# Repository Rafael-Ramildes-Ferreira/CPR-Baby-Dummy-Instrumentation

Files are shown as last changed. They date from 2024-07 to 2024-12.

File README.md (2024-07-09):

# CPR-Baby-Dummy-Instrumentation
The goal is to apply sensors to verify CPR training on a Baby dummy. This is part of curse of Projeto Integrador (DAS5104) in UFSC, 2024, 1st semester.

The prject started at 2023/2 and the code made that semester can be seen [here](https://github.com/PSCoes/Projeto_Integrador).

The ESP code was developed using [Platform.io](https://platformio.org)

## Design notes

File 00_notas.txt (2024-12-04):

-(ptrdiff_t)boxq->tail era pra dar menor que zero para indexar boxq->queue, mas está dando positivo, o que dá LoadProhibited.
O próprio endereço de boxq->queue está dando errado.

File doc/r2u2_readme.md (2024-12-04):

# Using R2U2 on ESP32
The code used is provided in . However it is a demostration made to run in Linux. In order to run it in ESP32, some changes had to be done in the source code, such as the following:

### Padding
Paddings ware added to structures to combat differences in memory alignment. These structures are:
- `r2u2_mltl_instruction_t`
- `r2u2_boxq_t`     
- `r2u2_instruction_t`

Beyond adding the paddings in the struct definition it is also necessary to add it when the structrue is created with {**values}
Tests ware only made in past time formulas, some other structures may also need padding when different formulas are used

### Memory bound sizes
Standard monitor implementation is to big for the internal memory of most microcontrollers, so alternatives sizes ware added to implement the monitor and are know used in the library code in place of the old larger values.
These values ware placed as defines in `internals/bounds.h`

----

This is still not a complete list, more changes may be necessary.

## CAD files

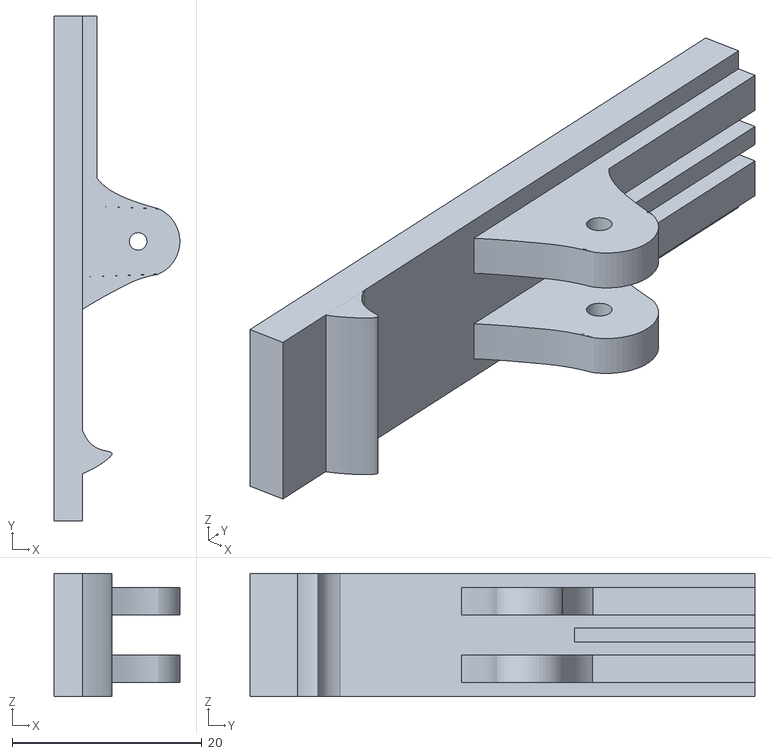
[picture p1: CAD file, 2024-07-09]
hardware/conector clip/pt_baixo_1_5mm.stl
13.2 x 53.2 x 13.0

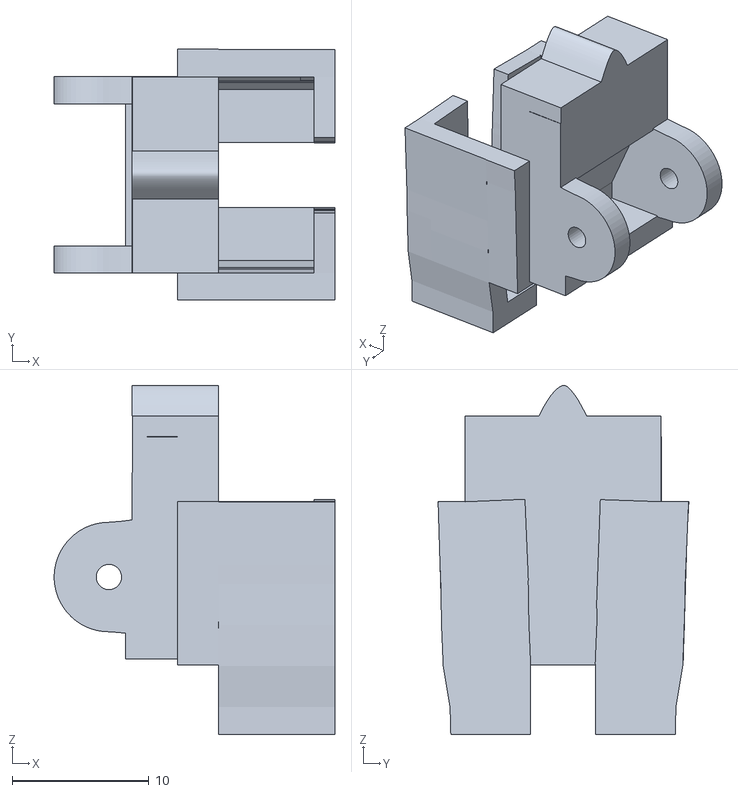
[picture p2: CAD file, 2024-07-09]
hardware/conector clip/pt_cima_1mm.stl
20.5 x 18.3 x 25.5

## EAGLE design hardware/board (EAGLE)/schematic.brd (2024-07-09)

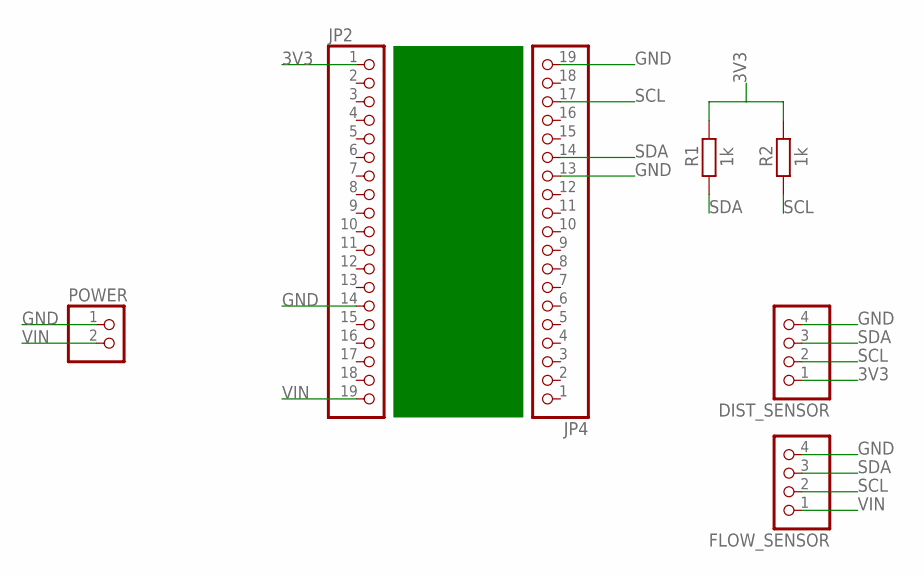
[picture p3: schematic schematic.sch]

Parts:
DIST_SENSOR: PINHD-1X4; 1X04
FLOW_SENSOR: PINHD-1X4; 1X04
JP2, JP4: PINHD-1X19; 1X19
POWER: PINHD-1X2; 1X02
R1, R2: 1k; 0207/10

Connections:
3V3: DIST_SENSOR.1, JP2.1, R1.2, R2.2
GND: DIST_SENSOR.4, FLOW_SENSOR.4, JP2.14, JP4.13, JP4.19, POWER.1
SCL: DIST_SENSOR.3, FLOW_SENSOR.3, JP4.17, R2.1
SDA: DIST_SENSOR.2, FLOW_SENSOR.2, JP4.14, R1.1
VIN: FLOW_SENSOR.1, JP2.19, POWER.2

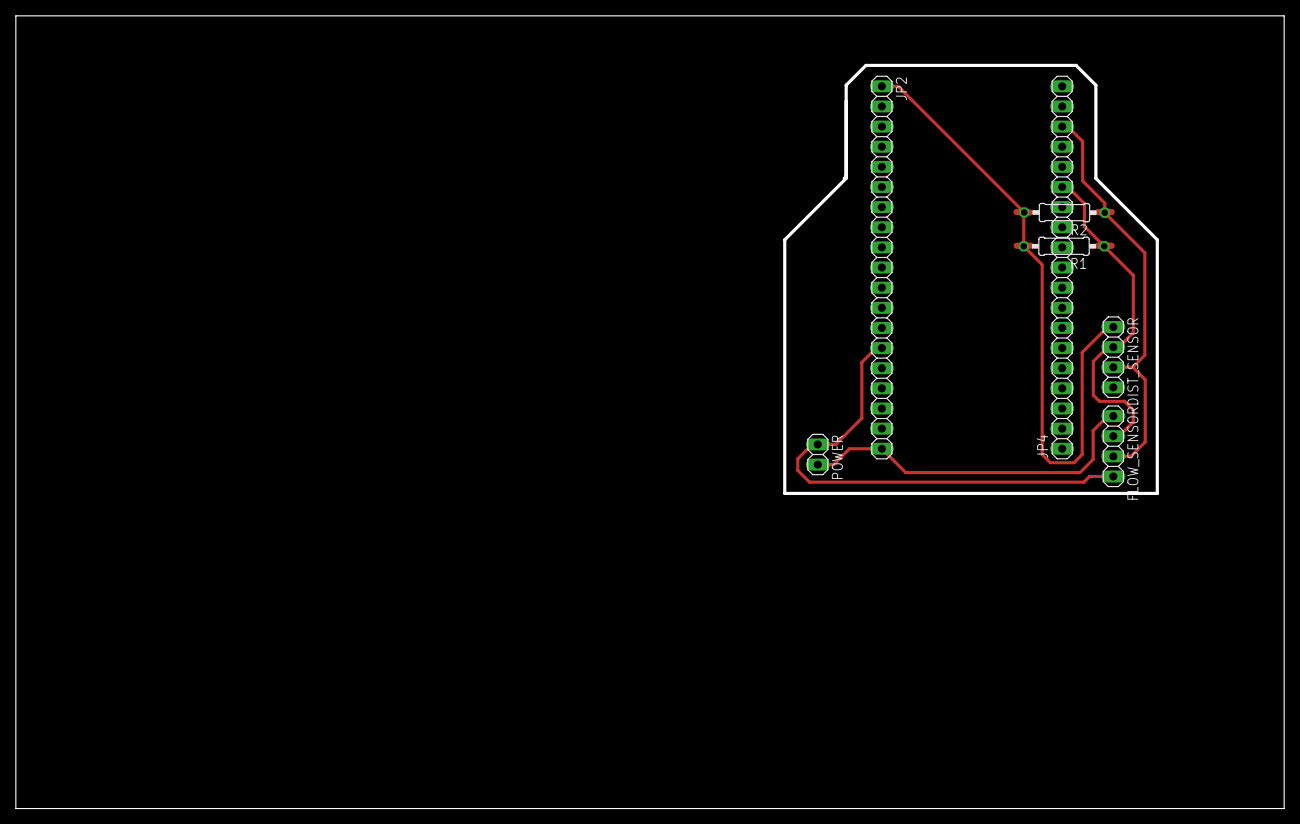
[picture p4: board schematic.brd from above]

Board: 2 copper layers, 160.0 x 100.0 mm, 7 parts (0 on the bottom side), 5 nets.

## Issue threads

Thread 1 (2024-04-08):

Measured value in sensor error

Rafael-Ramildes-Ferreira, 2024-04-08:
Find out why the measured value was set to 200 when error happens in the distance sensor reading

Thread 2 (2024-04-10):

Fix timer overflow

Rafael-Ramildes-Ferreira, 2024-04-10:
millis can overflow, it's used in last_peak and last_valley
- [ ] Fix overflow
- [ ] Change data type

Rafael-Ramildes-Ferreira, 2024-07-01:
"[...] Esse número irá sofrer overflow (chegar ao maior número possível e então voltar pra zero), após aproximadamente 50 dias."
[Arduino reference](https://www.arduino.cc/reference/pt/language/functions/time/millis/)

Closed 2024-07-01.

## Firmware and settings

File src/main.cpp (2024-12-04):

/**
 * ATTENTION: YOU NEED TO CHEAT!!!
 * You may need to coment out the lines:
 * 
 * 69:  if (read8(VL6180X_REG_IDENTIFICATION_MODEL_ID) != 0xB4) {
 * 70:    return false;
 * 71:  }
 * 
 * from .pio\libdeps\nodemcu-32s\Adafruit_VL6180X\Adafruit_VL6180X.cpp
 * 
 * ATTENTION: You need to make a fill changes for R2U2 to work
 * Add paddings to the structs
 * You also need to change cases like the following:
 * - boxq->queue = &(elements[(R2U2_MAX_BOXQ_BYTES / sizeof(r2u2_boxq_intvl_t)) - instr->memory_reference]);
 * + boxq->queue = &(elements[(NUN_OF_BOXQ_BYTES / sizeof(r2u2_boxq_intvl_t)) - instr->memory_reference]);
 * in `past_time.c` (add the define to the library)
*/
#include "buildconfig.h"
#include "main.h"
#include "wireless.h"
#include "air_flow.h"
#include "chest_compressions.h"
#include "timerinterruption.h"
#include "soc/rtc_wdt.h"
#include "r2u2.h"
#include "rv_monitor.h"
#include <stdio.h>

#define PADDING {0,0,0,0}

BlueToothCommunicator *communicator;
ChestCompression *chest;
AirFlow air_flow;
Runtime_Monitor monitor;

TimerInterruption trace_export(TIMER_3,30);

void request_trace(void);


bool trace_requested = false;
long int monitor_timeStamp = -1;
bool data_sent = false;
double distance = 0.0;
double air = 0.0;


void setup() {
  rtc_wdt_feed();

#ifdef DEBUG
  Serial.begin(115200);
#endif

  delay(1);

#ifdef DEBUG
  Serial.println("Começando");
#endif
  
  chest = new ChestCompression();
  if(!(chest->begin())){
    error_handler();
  }
#ifdef DEBUG
  Serial.println("chest.begin()");
#endif

  air_flow.begin();
#ifdef DEBUG
  Serial.println("air_flow.begin();");
#endif

  communicator = new BlueToothCommunicator();
#ifdef DEBUG
  Serial.println("new BlueToothCommunicator();");
#endif

  trace_export.set_timer_interrupt(request_trace);
#ifdef DEBUG
  Serial.println("trace_export.set_timer_interrupt(request_trace);");
#endif
  
  communicator->begin(AVAILABLE_SENSORS);
#ifdef DEBUG
  Serial.println("communicator->begin(AVAILABLE_SENSORS);");
#endif

  // Starts the monitor
  r2u2_status_t status = monitor.begin();
  if(status != R2U2_OK){
    printf("Monitor initialization falied: &d", status);
    while (1);
  }
  Serial.println("monitor.begin()");
  monitor.printInstr();
  
}

void loop() {
  /* Sensors read */
  #ifdef DISTANCE_SENSOR
  // Distance
  rtc_wdt_feed();
  chest->calc_distance();
  #endif  // DISTANCE_SENSOR

  #ifdef FREQUENCY_ON_ESP
  // Frequency
  rtc_wdt_feed();
  chest->calc_frequency();  
  #endif  // FREQUENCY_ON_ESP
  
  // Air Flow
  #ifdef AIR_FLOW_SENSOR
  rtc_wdt_feed();
  air_flow.readFlow();
  #endif  // AIR_FLOW_SENSOR


  /* Trace data export */
  if(trace_requested){
    monitor_timeStamp++;

    trace_requested = false;

    monitor.update_float_signal(0,distance);
    distance = chest->get_distance();
    monitor.update_float_signal(1,distance);
    monitor.update_float_signal(2,air);
    air = air_flow.get_flow();
    monitor.update_float_signal(3,air);
    monitor.update_bool_signal(4,data_sent);
    data_sent = false;
    monitor.tic();
    printf("----------\n");
    
    #ifdef DEBUG
    #ifdef DISTANCE_SENSOR
    printf("[%d] Distance: %lf\n",monitor_timeStamp,chest->get_distance());
    #endif  // DISTANCE_SENSOR
    
    #ifdef FREQUENCY_ON_ESP
    printf("[%d] Frequency: %lf\n",monitor_timeStamp,chest->get_frequency());
    #endif  // FREQUENCY_ON_ESP

    #ifdef AIR_FLOW_SENSOR
    printf("[%d] Air_flow: %lf\n",monitor_timeStamp, air_flow.get_flow());
    #endif  // AIR_FLOW_SENSOR
    #endif  // DEBUG
  }


  /* Wireless comunication */
  if(communicator->request_to_send)
  {
    data_sent = true;
    rtc_wdt_feed();
    communicator->update();
    #ifdef DEBUG
    printf("[%d] Request_To_Send\n",monitor_timeStamp);
    #endif  // DEBUG
  }
}


void IRAM_ATTR request_trace(void){
  trace_requested = true;
}


void error_handler(){
  while (1)
  {
    /* Does nothing */
    /* It could blink a led or something, but the watch dog will probably restart it*/
    Serial.println("ERROR!!!");
  }
  
}

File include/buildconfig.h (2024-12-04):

#ifndef _BUILDCONFIG_H
#define _BUILDCONFIG_H

#define DEBUG
// #ifdef DEBUG
#include <Arduino.h>
// #endif

// #define DISTANCE_SENSOR
// #define FREQUENCY_ON_ESP
// #define AIR_FLOW_SENSOR


#ifndef DISTANCE_SENSOR
#undef FREQUENCY_ON_ESP
#endif

#if defined(DISTANCE_SENSOR) && defined(AIR_FLOW_SENSOR)
#define AVAILABLE_SENSORS	chest,&air_flow
#elif defined(DISTANCE_SENSOR) && !defined(AIR_FLOW_SENSOR)
#define AVAILABLE_SENSORS	chest,nullptr
#elif !defined(DISTANCE_SENSOR) && defined(AIR_FLOW_SENSOR)
#define AVAILABLE_SENSORS	nullptr,&air_flow
#else
#define AVAILABLE_SENSORS	nullptr,nullptr
#endif

#endif

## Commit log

2024-04-08 Add: Distance sensor library included and sensor initialization
2024-04-08 Add: Sensor read function
2024-04-08 Fix: Ignores failed sensor readings
    [main.cpp]
2024-04-15 Add: Last valley implementation and some debugging printing
2024-04-15 Add: Timer interrupt to send wireles signals
2024-04-16 WatchDog is working as expected - WE NEED TO TEST THE DISTANCE SENSOR
2024-04-16 Add: Timer interrupt configuration generalized to be used with wifi and bluetooth
2024-04-17 Fix: Now it expects ChestCompression to be a class
    [main.cpp, wireless.cpp]
2024-04-17 Fix: Wifi communicator turned into a class
    [main.cpp, wireless.cpp, wireless.h]
2024-04-17 Fix: Timer Interrupt clas created to wrap ESP8266 ITimer class
    [wireless.cpp, wireless.h]
2024-04-17 Fix: Setting of ssid
    [wireless.cpp]
2024-04-22 Deviation threshold configured (tests ceased due to sensor not conecting - maybe because of the wirering?)
2024-04-22 Fix: Integration fixes and ChestCompression Getters defined
    [wireless.cpp, wireless.h]
2024-05-26 platformio.ini configured to use NodeMCU ESP32s
2024-05-27 Gets rid of the watchdog reset calls
    [main.cpp]
2024-05-27 Configures time interruption to the NodeMCU EPS32
2024-05-27 Wireless communicator class adapted to ESP 32s
2024-05-28 Add: Air sensor class
2024-05-29 May 29th, 2024: Still under testing, Stopped reading VL6180, added a I2C scanner that confirmed the expected IDs
2024-05-29 I2C_Scanner.cpp moved to new directory ´utils´, since ´test´ is for test codes
    And news: I can't communicate with VL6180X with the example library code neither
2024-05-29 Distance sensor readings ´fixed´ (in a hacky way)
    [main.cpp]
2024-06-03 No longer yields communication error
    [main.cpp]
2024-06-03 Unnecessaries includes trimed, It is not seting up the timer interrupt
2024-06-04 Configured to interrupt, but it's pinicing
2024-06-04 Interrupt seems to be fixed
    [main.cpp, wireless.cpp, wireless.h]
2024-06-13 No longer initializing the communicator with nullptrs
    request_to_send moved to a variable, maybe revert this later
    [main.cpp, wireless.cpp, wireless.h]
2024-06-13 Tested and transmitting through WiFi, printings deleted, not reading right
2024-06-17 Dist Sensor readings review, printing error code when DEBUG flag is defined
2024-06-18 Old implementation of timer interrupt deleted and a idea of ISR change was added
2024-06-18 request_to_send became part of the class again and measurements of the sensors are made before start the Wi-Fi transmission
2024-06-18 In send wifi function, Serial.println moved after the WiFi transmission
2024-06-26 Bluetooth funcionando, sensor de fluxo desconectado pois queimou
2024-07-03 Frequency calculation that was previously tested on Arduino IDE brought to Platformio
2024-07-03 Fix mistakes during confict resolutions
    [main.cpp]
2024-07-03 Parameters tested in Arduino IDE brought to Platform.io (I forgot to bring'em earlier
2024-07-03 Debug printing fixed
2024-07-05 Revert "Bluetooth updates are now called by ISR"
    This reverts commit 139edabfa6c8350be81523d6a431ee11ffcf9e10.
    [main.cpp, wireless.cpp]
2024-07-05 Air flow class operation standardized
    It now has a I2C reading method - readFlow() - and a stored value get method - get_flow()
    So it now has to store the value
    It was also added to the main.c code
2024-07-05 Using flags to activate and deactivate the usage of sensors
2024-07-08 Bluetooth class no longer use so many statics
    [wireless.cpp, wireless.h]
2024-07-08 Makes sure to start advertizing again after a disconnect and that the led is turned off when disconnected
    The advertiziment thing seems to have helped with reconnecting with nRF Connect after a disconnection
2024-07-09 Added Eagle's board file
    [schematic.brd, schematic.sch]
2024-07-09 Added the air flow sensor conector clip
    [pt_baixo_1_5mm.stl, pt_cima_1mm.stl]
2024-10-31 Blobing hello world (both with Serial.println and with printf)
2024-11-13 Makes a functional allocation of the monitor struct and makes the monitor run (giving wrong results yet)
    [main.cpp]
2024-11-22 Fix paddin issues with instruction structure: malloc is no longer needed and the program doesn't crash when there are more tha one requirement
    - It still gives the same result for both expressions when it shouldn't. Issue: Fix duplicated results
    - malloc is still used for the signal vectors (I don't know of a nother way) Issue: Verify correct way of allocating space for signal vector
    - I haven't checked if other paddings ware causing problems. I should check all relevant structures
    malloc for boxq and scq are no longer needed since the space for this structures are alocated during the monitor initialization, the padding difference from Linux to ESP32 ware causing mismatches that made the R2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
    [main.cpp]
2024-11-23 Fix requirement tag printing in the out_func, plus configure it to run with floats
    - Still only returns one of the requirements correctly
2024-11-23 Changes the comment at the begining of the main file for documentation
    Meanwhile changes ware made to R2U2 lib so it would work on ESP32:
    ### Padding
    Paddings ware added to structures to combat differences in memory alignment. These structures are:
    -
    2u2_mltl_instruction_t
    -
    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
2024-11-24 Fix float variable initialization (allocing the right size)
    [main.cpp]
2024-11-25 Quality of life improvement on enabling and disabling sensors
2024-11-25 Adds the possibility of configuring two timer interrupts
2024-11-25 Adds a second timer interrupt to export the trace
2024-11-25 Fix time stamp (it wasn't being incremented) and configures to run, trace data was collected
    [buildconfig.h, main.cpp]
2024-11-25 Funcionando para a apresentação
2024-12-04 Keeps the class even when the sensor is disable to help with the RV
